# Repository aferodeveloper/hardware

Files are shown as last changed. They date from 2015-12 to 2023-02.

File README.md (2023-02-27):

## Afero ASR-1 Secure Radio Module Library ##

- **ASR-1 library files** provided in Allegro, Eagle, and OrCad Capture file formats.

## Afero Module Development Board ##

- **Modulo layout** in Allegro 16.6 file format.
- **Modulo schematic** in Orcad Capture file format.

## Afero Plinto Development Board ##

- **Plinto layout** in Eagle file format.
- **Plinto schematic** in Eagle file format.

### More Information ###

<http://developer.afero.io>

### License ###

Copyright 2015 Afero, Inc.

Licensed under the Creative Commons Attribution 4.0 International Public 
License (the "License"); you may not use this file except in compliance 
with the License. You may obtain a copy of the License at:

<http://creativecommons.org/licenses/by/4.0/legalcode>

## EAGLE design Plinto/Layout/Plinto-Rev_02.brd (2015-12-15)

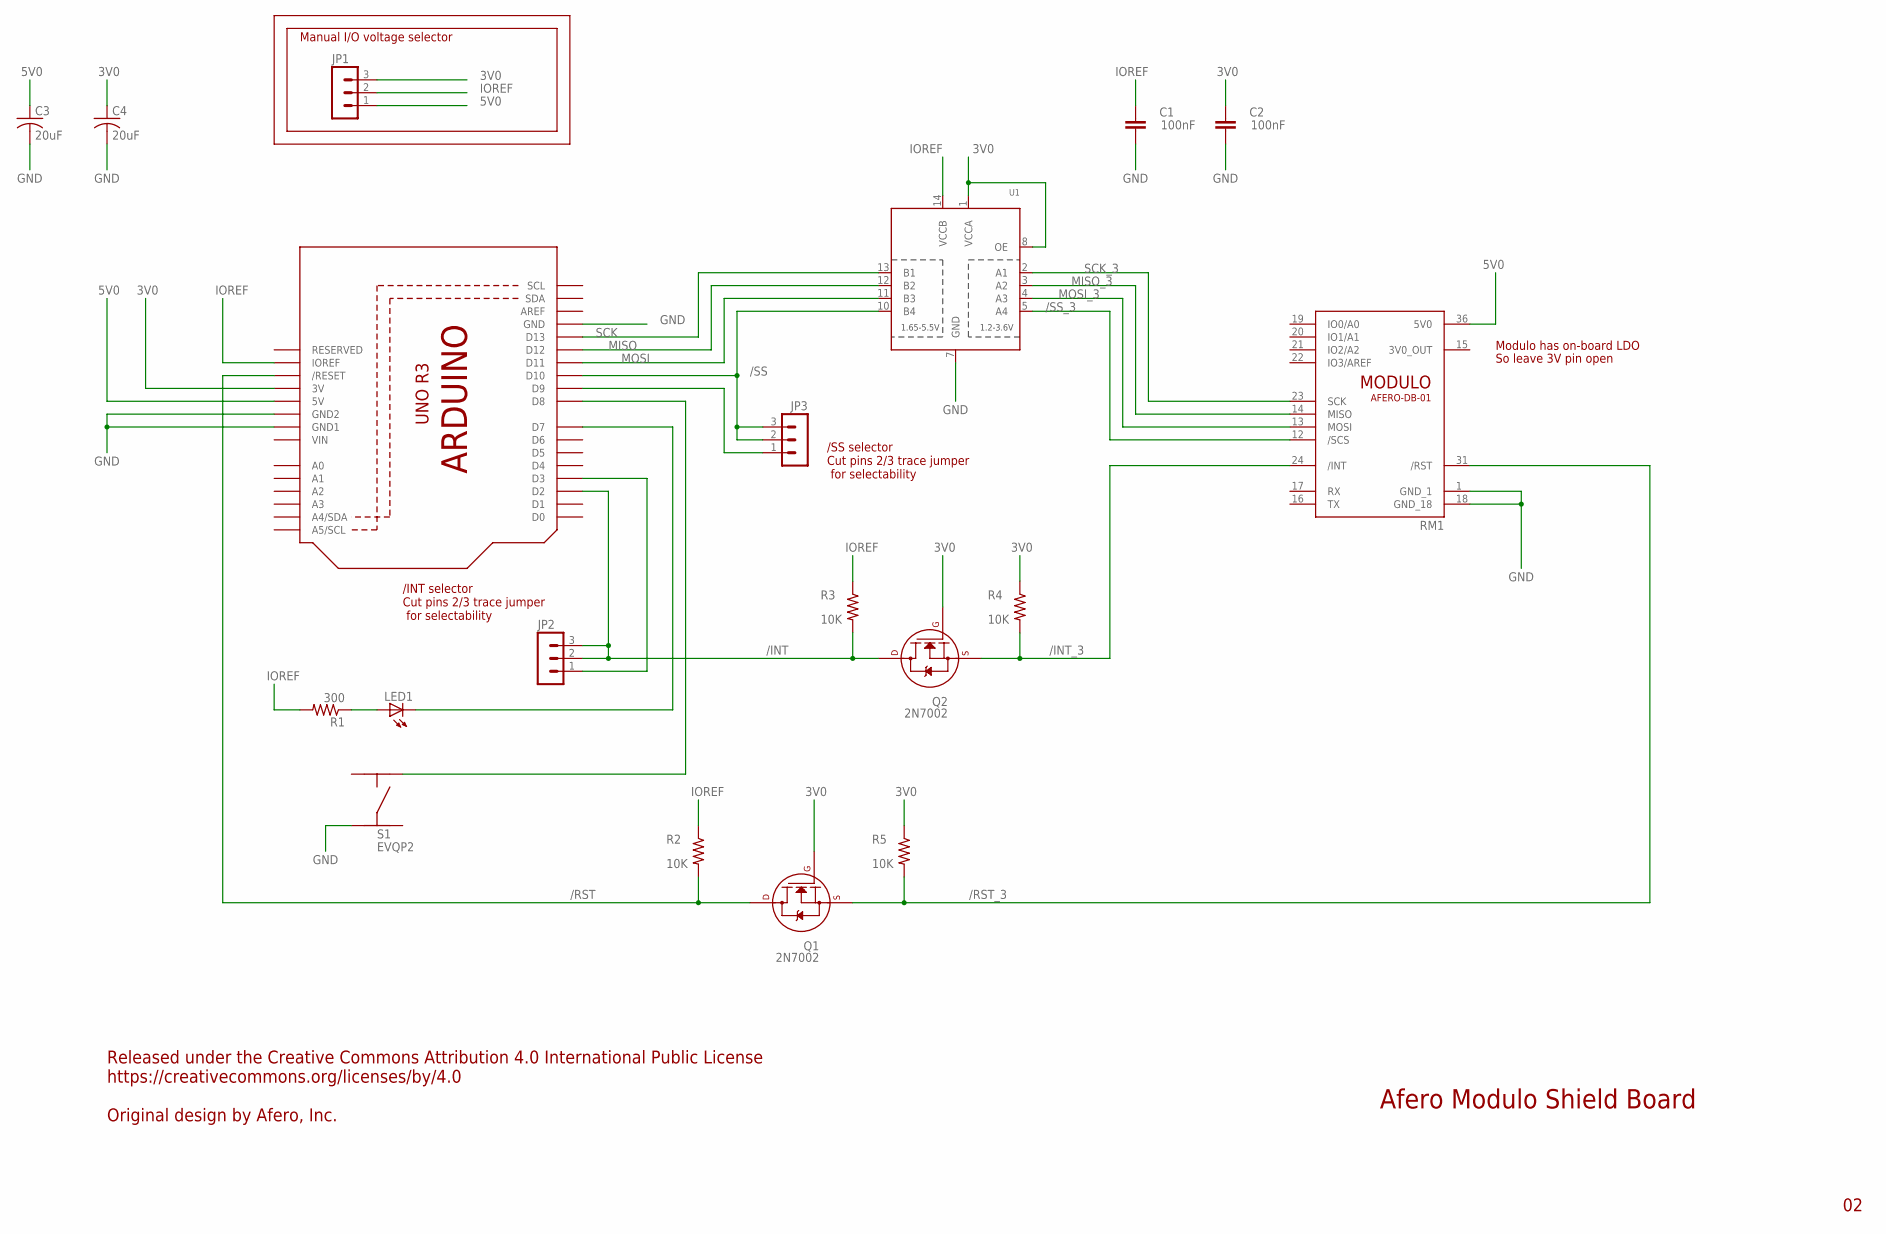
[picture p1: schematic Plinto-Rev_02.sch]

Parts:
C1, C2: 100nF; C0402
C3, C4: 20uF; C0805
JP1, JP2, JP3: 3PIN_JMPR
LED1: LEDCHIPLED_0603; CHIPLED_0603
Q1, Q2: 2N7002; SOT-23
R1: 300; R0402
R2, R3, R4, R5: 10K; R0402
RM1: MODULOAFERO-DB-01; MODULO
S1: EVQP2
U1: TXB0104PWR; TSSOP14
U$1: ARDUINO_UNO_R3KIBANVERSION; ARDUINO_R3

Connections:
3V0: C2.1, C4.1, JP1.3, Q1.1 (G), Q2.1 (G), R4.1, R5.1, U1.1 (VCCA), U1.8 (OE), U$1.3V
3V0_OUT: RM1.15 (3V0_OUT)
5V0: C3.1, JP1.1, RM1.36 (5V0), U$1.5V
/INT: JP2.2, JP2.3, Q2.3 (D), R3.2, U$1.D2
/INT_3: Q2.2 (S), R4.2, RM1.24 (/INT)
/RST: Q1.3 (D), R2.2, U$1.RESET (/RESET)
/RST_3: Q1.2 (S), R5.2, RM1.31 (/RST)
/SS: JP3.2, JP3.3, U1.10 (B4), U$1.D10
/SS_3: RM1.12 (/SCS), U1.5 (A4)
GND: C1.2, C2.2, C3.2, C4.2, RM1.1 (GND_1), RM1.18 (GND_18), S1.P$4, U1.7 (GND), U$1.GND, U$1.GND1, U$1.GND2
IOREF: C1.1, JP1.2, R1.2, R2.1, R3.1, U1.14 (VCCB), U$1.IOREF
MISO: U1.12 (B2), U$1.D12
MISO_3: RM1.14 (MISO), U1.3 (A2)
MOSI: U1.11 (B3), U$1.D11
MOSI_3: RM1.13 (MOSI), U1.4 (A3)
unnamed: LED1.A, R1.1
unnamed: LED1.C, U$1.D7
unnamed: JP2.1, U$1.D3
unnamed: S1.P$1, U$1.D8
unnamed: JP3.1, U$1.D9
SCK: U1.13 (B1), U$1.D13
SCK_3: RM1.23 (SCK), U1.2 (A1)
VIN: U$1.VIN

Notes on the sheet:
Manual I/O voltage selector
Modulo has on-board LDO
So leave 3V pin open
/INT selector Cut pins 2/3 trace jumper for selectability
Released under the Creative Commons Attribution 4.0 International Public License https://creativecommons.org/licenses/by/4.0 Original design by Afero, Inc.
/SS selector Cut pins 2/3 trace jumper for selectability
Afero Modulo Shield Board

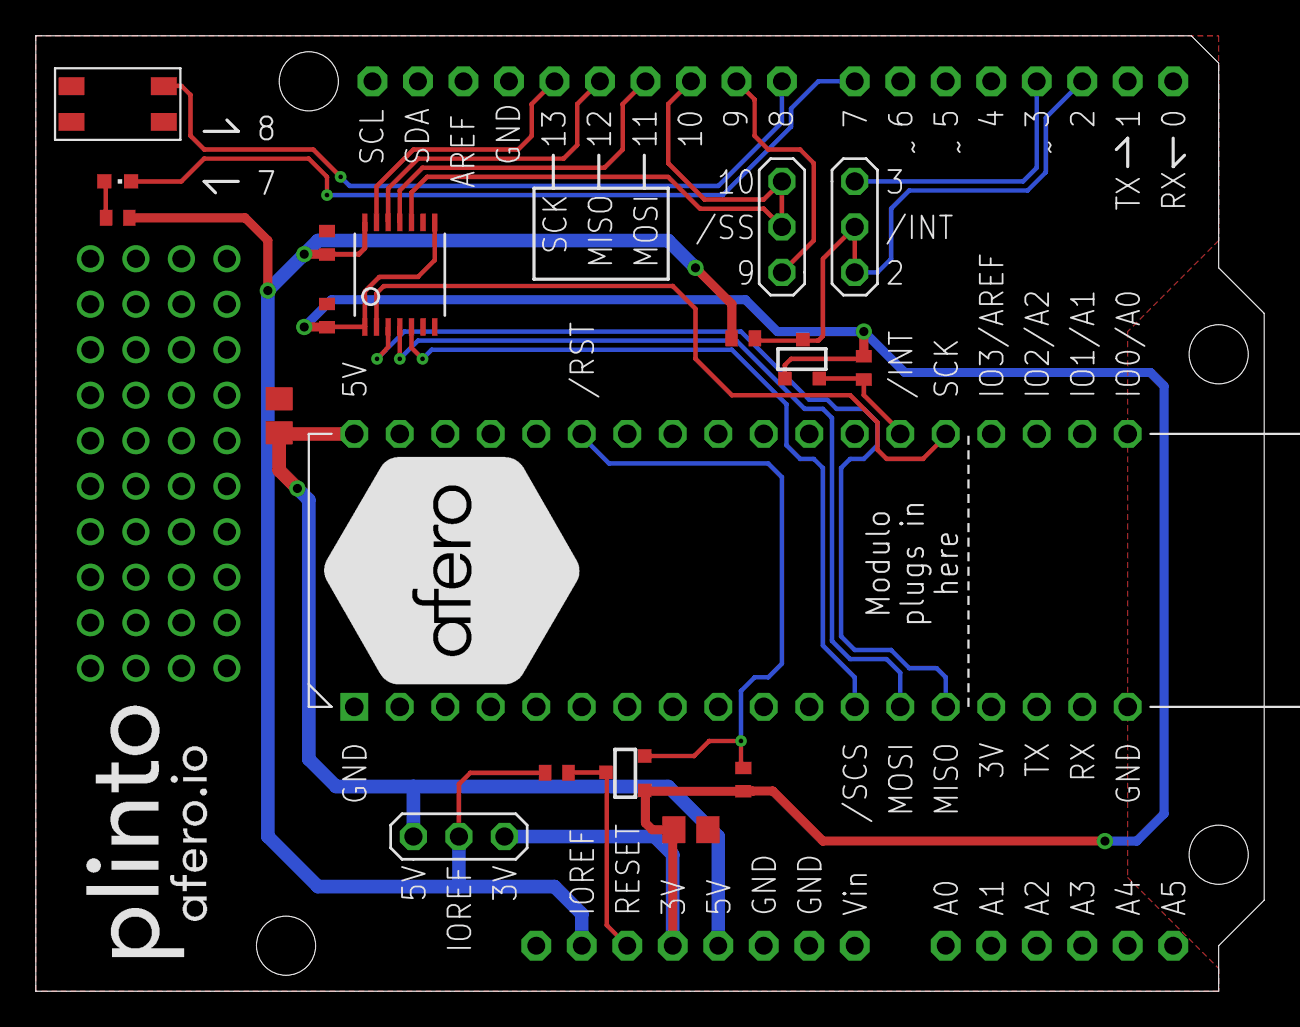
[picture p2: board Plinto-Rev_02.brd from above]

Board: 2 copper layers, 68.6 x 53.3 mm, 20 parts (0 on the bottom side), 21 nets.

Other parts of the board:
U$2: AFERO_LOGO_SMALL

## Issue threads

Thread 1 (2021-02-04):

Schematics for modulo-2 is missing here. Could you please update that.

adithyayuri, 2021-02-04:
Schematics for modulo-2 is missing here. Could you please update that ?

Closed 2021-03-10.

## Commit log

2015-12-15 Initial checkin of Afero hardware files.
    [Modulo-Rev_03.DSN, Modulo-Rev_03.brd, Plinto-Rev_02.brd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]
2016-05-16 Add Modulo schematic in PDF format for reference
2016-05-16 update board files to rev_04
    [Modulo-Rev_03.DSN, Modulo-Rev_03.brd, Modulo-Rev_04.DSN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]
